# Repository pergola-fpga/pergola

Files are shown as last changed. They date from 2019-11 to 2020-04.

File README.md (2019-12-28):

# Pergola FPGA

The Pergola FPGA board is a low-cost, open-source FPGA development board featuring the Lattice ECP5 FPGA.

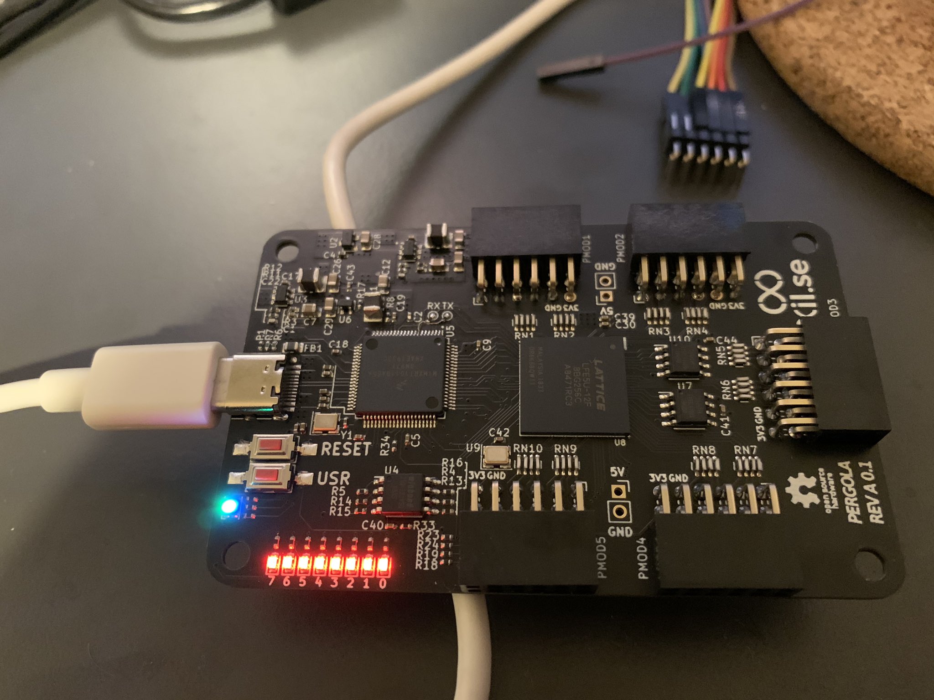
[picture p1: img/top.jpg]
Pergola FPGA top view


# Current status

## RevA 0.1

A handful of units have been built for initial test and bringup populated with LFE5U-12F-8BG256C.

It has been tested and works if the fixes below are applied.

### Errata:

- iMX ROM bootloader freezes because the UART RX pin is pulled
   low by the FPGA during boot. (FPGA pin is PL35B_VREF_1_6)
   A 4K7 pull-up is probably not enough, the voltage drops to 2.9V.
   Workaround: Bodge a 1K pull-up between UART_RX and 3V3.
- Wrong load caps for the xtal. Should be 20pF.
- SWD IO and CLK are swapped on the silk.
- IMX_BOOT_MODE_0 and IMX_BOOT_MODE_1 are swapped on the silk.
- A 1K pull-down is on the `~FPGA_HOLD~` net to allow the iMX to use the flash exclusively during boot-up.

# Firmware
TODO.

Currently I have a very ugly test project that can be loaded into the iMX's RAM using the ROM bootloader. This will open up a CDC interface that can be used to send a bitstream to the FPGA.

Currently working on porting the UF2 bootloader in order to update the firmware easily using USB and not having to use the SWD pins.

Current *horrible* hack is located over at [git.xil.se](https://git.xil.se/kbeckmann/pergola_fw) and contains a prebuilt binary.

The firmware will expose a cdc_acm device over USB. To program a bitstream, you simply have to write the number of bytes it is, followed by a newline (`\n`), followed by the bitstream.

# Getting started

- Clone my fork of the imx usb loader project:
```
git clone https://github.com/kbeckmann/imx_usb_loader && cd imx_usb_loader
```
- Checkout the `imxrt1010` branch:
```
git checkout imxrt1010
```
- Build it:
```
make
```
- Clone this repository and change to the firmware directory: (firmware is built from https://git.xil.se/kbeckmann/pergola_fw)
```
cd .. && git clone https://github.com/pergola-fpga/pergola && cd pergola/firmware
```
- Run the loader:
```
../../imx_usb_loader/imx_usb
```
. You might have to run it with `sudo`.
- Check `dmesg` to see if you got a cdc_acm device, e.g. `ttyACM0`
- Now you'll be able to send a bitstream to the board:
```
export ACM_DEVICE=/dev/ttyACM0
export PROGRAM_BIN=path/to/your/top.bin

# If you don't have setup udev rules
sudo chown $UID:$GID $ACM_DEVICE

# Configure the ACM device to be raw, this prevents weird stuff from happening when we send raw binary data.
stty -F $ACM_DEVICE 300 raw -clocal -echo icrnl;
sleep 0.01;
cat $ACM_DEVICE &;
echo -n "$(stat -c%s $PROGRAM_BIN)\n" > $ACM_DEVICE;
cp $PROGRAM_BIN $ACM_DEVICE; sync
```

- This should generate the following output more or less:
```
Reading 582369 bytes
READ_ID: ff ff ff ff 21 11 10 43

Done programming. FPGA_DONE=1
P E R G O L A

<bytes to load><\n>; Load bitstream to FPGA SRAM
```

- There is also an nmigen board definition in gateware/nmigen_wip/pergola.py

# How to contribute

Feel free to submit a PR, create an issue.

Discussion happens on [Gitter](https://gitter.im/pergola-fpga/Lobby) for the time being. You can also ping [@kbeckmann](https://twitter.com/kbeckmann) on Twitter.

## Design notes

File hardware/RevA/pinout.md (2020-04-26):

# PMOD Pinout RevA 0.1

```
-------- PMOD 1 ------ PMOD 2 ----
|                                 |
|                                 |P
|U                                |M
|S                                |O
|B                                |D
|                                 |3
|                                 |
-------- PMOD 5 ------ PMOD 4 ----

PMOD pinout, female header, front view

+--------------------------------------+
|3V3   GND      4      3      2      1 |
|3V3   GND      8      7      6      5 |
+--------------------------------------+

PMOD 1          TDP        TDP        TDP        TDP
+------------------------------------------------------+
|3V3   GND      PL20B      PL23B      PL26A      PL32B |
|3V3   GND      PL20A      PL23A      PL26B      PL32A |
+------------------------------------------------------+

PMOD 2          TDP        TDP        TDP        TDP
+------------------------------------------------------+
|3V3   GND      PL2A       PL5A       PL8B       PL14B |
|3V3   GND      PL2B       PL5B       PL8A       PL14A |
+------------------------------------------------------+

PMOD 3                                TDP
+------------------------------------------------------+
|3V3   GND      PT27A <DP> PT27B     PT22A      PT9B  |
|3V3   GND      PT29B <DP> PT29A     PT22B      PL11A |
+------------------------------------------------------+

PMOD 4          TDP
+------------------------------------------------------+
|3V3   GND      PT67A      PT60A      PT56A      PT49A |
|3V3   GND      PT67B      PT65B <DP> PT65A      PT53B |
+------------------------------------------------------+

PMOD 5          TDP        TDP        TDP        TDP
+------------------------------------------------------+
|3V3   GND      PR26A      PR23A      PR20A      PR14A |
|3V3   GND      PR26B      PR23B      PR20B      PR14B |
+------------------------------------------------------+

```

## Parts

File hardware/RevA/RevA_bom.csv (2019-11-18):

Reference | Quantity | Value | Footprint | Datasheet | LCSC | LCSC EUR | LCSC URL | Mouser | Mouser EUR | Mouser URL
C10 C15 C4 | 3 | 4u7 | Capacitor_SMD:C_0402_1005Metric |  | https://lcsc.com/product-detail/Multilayer-Ceramic-Capacitors-MLCC-SMD-SMT_SAMSUNG_CL21A226MOQNNNE_22uF-226-20-16V_C98190.html
C11 C14 | 2 | 4p7 | Capacitor_SMD:C_0402_1005Metric
C16 C20 C23 C3 C1 C17 C30 C33 C36 C38 C39 C31 C34 C32 C35 C37 C41 C42 C40 C43 C44 | 21 | 100n | Capacitor_SMD:C_0402_1005Metric
C19 C8 C13 C18 C9 C5 C2 | 7 | 220n | Capacitor_SMD:C_0402_1005Metric
C21 C22 | 2 | 22p | Capacitor_SMD:C_0402_1005Metric
C24 | 1 | 10u | Capacitor_SMD:C_0402_1005Metric |  | https://lcsc.com/product-detail/Multilayer-Ceramic-Capacitors-MLCC-SMD-SMT_SAMSUNG_CL21A226MOQNNNE_22uF-226-20-16V_C98190.html
C25 C27 C28 C7 C26 C29 C6 C12 | 8 | 22u | Capacitor_SMD:C_0805_2012Metric |  | C98190 | 0.0297 | https://lcsc.com/product-detail/Multilayer-Ceramic-Capacitors-MLCC-SMD-SMT_SAMSUNG_CL21A226MOQNNNE_22uF-226-20-16V_C98190.html
D1 | 1 | LED_ARGB | LED_SMD:LED_Cree-PLCC4_2x2mm_CW |  | C108793 | 0.0249 | https://lcsc.com/product-detail/Light-Emitting-Diodes-LED_FM-B2020RGBA-HG_C108793.html
D3 D4 D5 D6 D7 D8 D9 D2 | 8 | LED | LED_SMD:LED_0603_1608Metric |  | C84263 | 0.0111 | https://lcsc.com/product-detail/Light-Emitting-Diodes-LED_Red-LED-SMDLED-80-100mcd_C84263.html
FB1 | 1 | Ferrite_Bead | Inductor_SMD:L_0805_2012Metric |  | C88993 | 0.0183 | https://lcsc.com/product-detail/Ferrite-Beads-And-Chips_muRata_BLM21PG220SN1D_22R-25_C88993.html
H1 H2 H4 H3 | 4 | DNP | MountingHole:MountingHole_3.5mm
J1 | 1 | USB_C_Receptacle_USB2.0 | Connector_USB_Extra:USB_C_Receptacle_GT-USB-7010 | https://www.usb.org/sites/default/files/documents/usb_type-c.zip | C165948 | 0.2221 | https://lcsc.com/product-detail/USB-Type-C_Korean-Hroparts-Elec-TYPE-C-31-M-12_C165948.html
J2 | 1 | DNP Conn_02x02_Odd_Even | Connector_PinHeader_2.54mm:PinHeader_2x02_P2.54mm_Vertical_SMD
J3 J5 | 2 | DNP Conn_01x02 | Connector_PinSocket_2.54mm:PinSocket_1x02_P2.54mm_Vertical
J4 | 1 | DNP Conn_02x03_Odd_Even | Connector_PinHeader_2.54mm:PinHeader_2x03_P2.54mm_Vertical_SMD
JP2 JP1 JP3 JP4 JP5 JP6 JP9 JP8 JP7 | 9 | 4K7 | ecp5board:JP_3_0402_1005Metric |  | C105871 | 0.0005 | https://lcsc.com/product-detail/Chip-Resistor-Surface-Mount_4-7KR-4701-1_C105871.html
L2 L1 L3 | 3 | 4u7 1A | ecp5board:L_1008_1210 |  | C90319 | 0.0691 | https://lcsc.com/product-detail/Inductors-SMD_Taiyo-Yuden_CBC3225T4R7MR_Taiyo-Yuden-CBC3225T4R7MR_C90319.html
LOGO1 | 1 | Logo_Open_Hardware_Small | Symbol:OSHW-Logo_5.7x6mm_SilkScreen | ~
LOGO2 | 1 | Logo_Open_Hardware_Small | ecp5board:logo | ~
LOGO3 | 1 | Logo_Open_Hardware_Small | ecp5board:xil_logo_new | ~
PMOD1 PMOD2 PMOD3 PMOD4 PMOD5 | 5 | Conn_02x06_Top_Bottom | ecp5board:PMOD_Socket_2x06_P2.54mm_Horizontal |  | C239357 | 0.1299 | https://lcsc.com/product-detail/Pin-Header-Female-Header_Changjiang-Connectors-A2541HWR-2x6P_C239357.html
R1 | 1 | 100K | Resistor_SMD:R_0402_1005Metric
R10 | 1 | 18K | Resistor_SMD:R_0402_1005Metric
R12 | 1 | 3K3 | Resistor_SMD:R_0402_1005Metric
R2 R17 R3 R14 R13 R16 R15 | 7 | 10K | Resistor_SMD:R_0402_1005Metric
R35 | 1 | DNP | Resistor_SMD:R_0402_1005Metric
R4 | 1 | 1K | Resistor_SMD:R_0402_1005Metric
R5 R19 R18 R23 R24 R34 R25 R26 R27 R28 R29 R30 R31 R32 R20 R21 R22 R33 | 18 | 4K7 | Resistor_SMD:R_0402_1005Metric
R6 R7 | 2 | 5K1 | Resistor_SMD:R_0402_1005Metric
R8 | 1 | 30K | Resistor_SMD:R_0402_1005Metric
R9 R11 | 2 | 15K | Resistor_SMD:R_0402_1005Metric
RN2 RN4 RN3 RN6 RN8 RN7 RN10 RN9 RN1 RN5 | 10 | 22R_x4 | Resistor_SMD:R_Array_Convex_4x0603 |  | C309446 | 0.0075 | https://lcsc.com/product-detail/Others_YAGEO-AF124-JR-0722RL_C309446.html
SW1 SW2 | 2 | SW_Push | Button_Switch_SMD:SW_SPST_FSMSM |  | C118141 | 0.0307 | https://lcsc.com/product-detail/Tactile-Switches_Korean-Hroparts-Elec-K2-1107ST-A4SW-06_C118141.html
TP1 | 1 | RX | TestPoint:TestPoint_Pad_D1.0mm
TP2 | 1 | TX | TestPoint:TestPoint_Pad_D1.0mm
U1 U3 | 2 | SY8120B1ABC | Package_TO_SOT_SMD:SOT-23-6 | https://datasheet.lcsc.com/szlcsc/1811081220_Silergy-Corp-SY8120B1ABC_C88474.pdf | C88474 | 0.0557 | https://lcsc.com/product-detail/DC-DC-Converters_Silergy_SY8120B1ABC_SY8120B1ABC_C88474.html
U2 | 1 | XC6206P25 | Package_TO_SOT_SMD:SOT-23 | https://datasheet.lcsc.com/szlcsc/1810271312_Torex-Semicon-XC6206P252MR_C15906.pdf | C15906 | 0.0529 | https://lcsc.com/product-detail/Low-Dropout-Regulators-LDO_XC6206P252MR_C15906.html
U4 | 1 | SPI Flash W25Q128JVSIQ | ecp5board:SOA008-150-208mil | https://datasheet.lcsc.com/szlcsc/1811142111_Winbond-Elec-W25Q128JVSIQ_C97521.pdf | C97521 | 0.4692 | https://lcsc.com/product-detail/FLASH_Winbond-Elec-W25Q128JVSIQTR_C97521.html
U5 | 1 | MIMXRT1011DAE5A | Package_QFP:LQFP-80_12x12mm_P0.5mm |  |  |  |  | 771-MIMXRT1011DAE5A | 2.95 | https://www.mouser.se/ProductDetail/NXP-Semiconductors/MIMXRT1011DAE5A
U6 | 1 | MAX803SQ308T1G | Package_TO_SOT_SMD:SOT-323_SC-70 | https://datasheet.lcsc.com/szlcsc/1809111625_ON-Semicon-MAX803SQ308T1G_C233650.pdf | C233650 | 0.1589 | https://lcsc.com/product-detail/Microprocessor-Microcontroller-Supervisors_ON-Semicon_MAX803SQ308T1G_ON-Semicon-ON-MAX803SQ308T1G_C233650.html
U7 U10 | 2 | SPI RAM LY68L6400SLIT | Package_SO:SOIC-8_3.9x4.9mm_P1.27mm | https://datasheet.lcsc.com/szlcsc/1809140531_Lyontek-Inc-LY68L6400SLIT_C261881.pdf | C261881 | 0.4665 | https://lcsc.com/product-detail/RAM_Lyontek-Inc-LY68L6400SLIT_C261881.html
U8 | 1 | LFE5U-12F-6BG256C | w_smd_bga:cabga256 |  |  |  |  | 842-LFE5U12F6BG256C | 4.96 | https://www.mouser.se/ProductDetail/Lattice/LFE5U-12F-6BG256C
U9 | 1 | 16MHz 20ppm | Crystal:Crystal_SMD_3225-4Pin_3.2x2.5mm |  | C387369 | 0.2984 | https://lcsc.com/product-detail/SMD-Oscillators-XO_Shenzhen-SCTF-Elec-S3D16-000000B20F30T_C387369.html
Y1 | 1 | 24MHz 10ppm | Crystal:Crystal_SMD_3225-4Pin_3.2x2.5mm |  | C164058 | 0.0642 | https://lcsc.com/product-detail/SMD-Crystal-Resonators_Zhejiang-Abel-Elec-SMD-3225-4P24MHZ12PF10PPM-40-85_C164058.html

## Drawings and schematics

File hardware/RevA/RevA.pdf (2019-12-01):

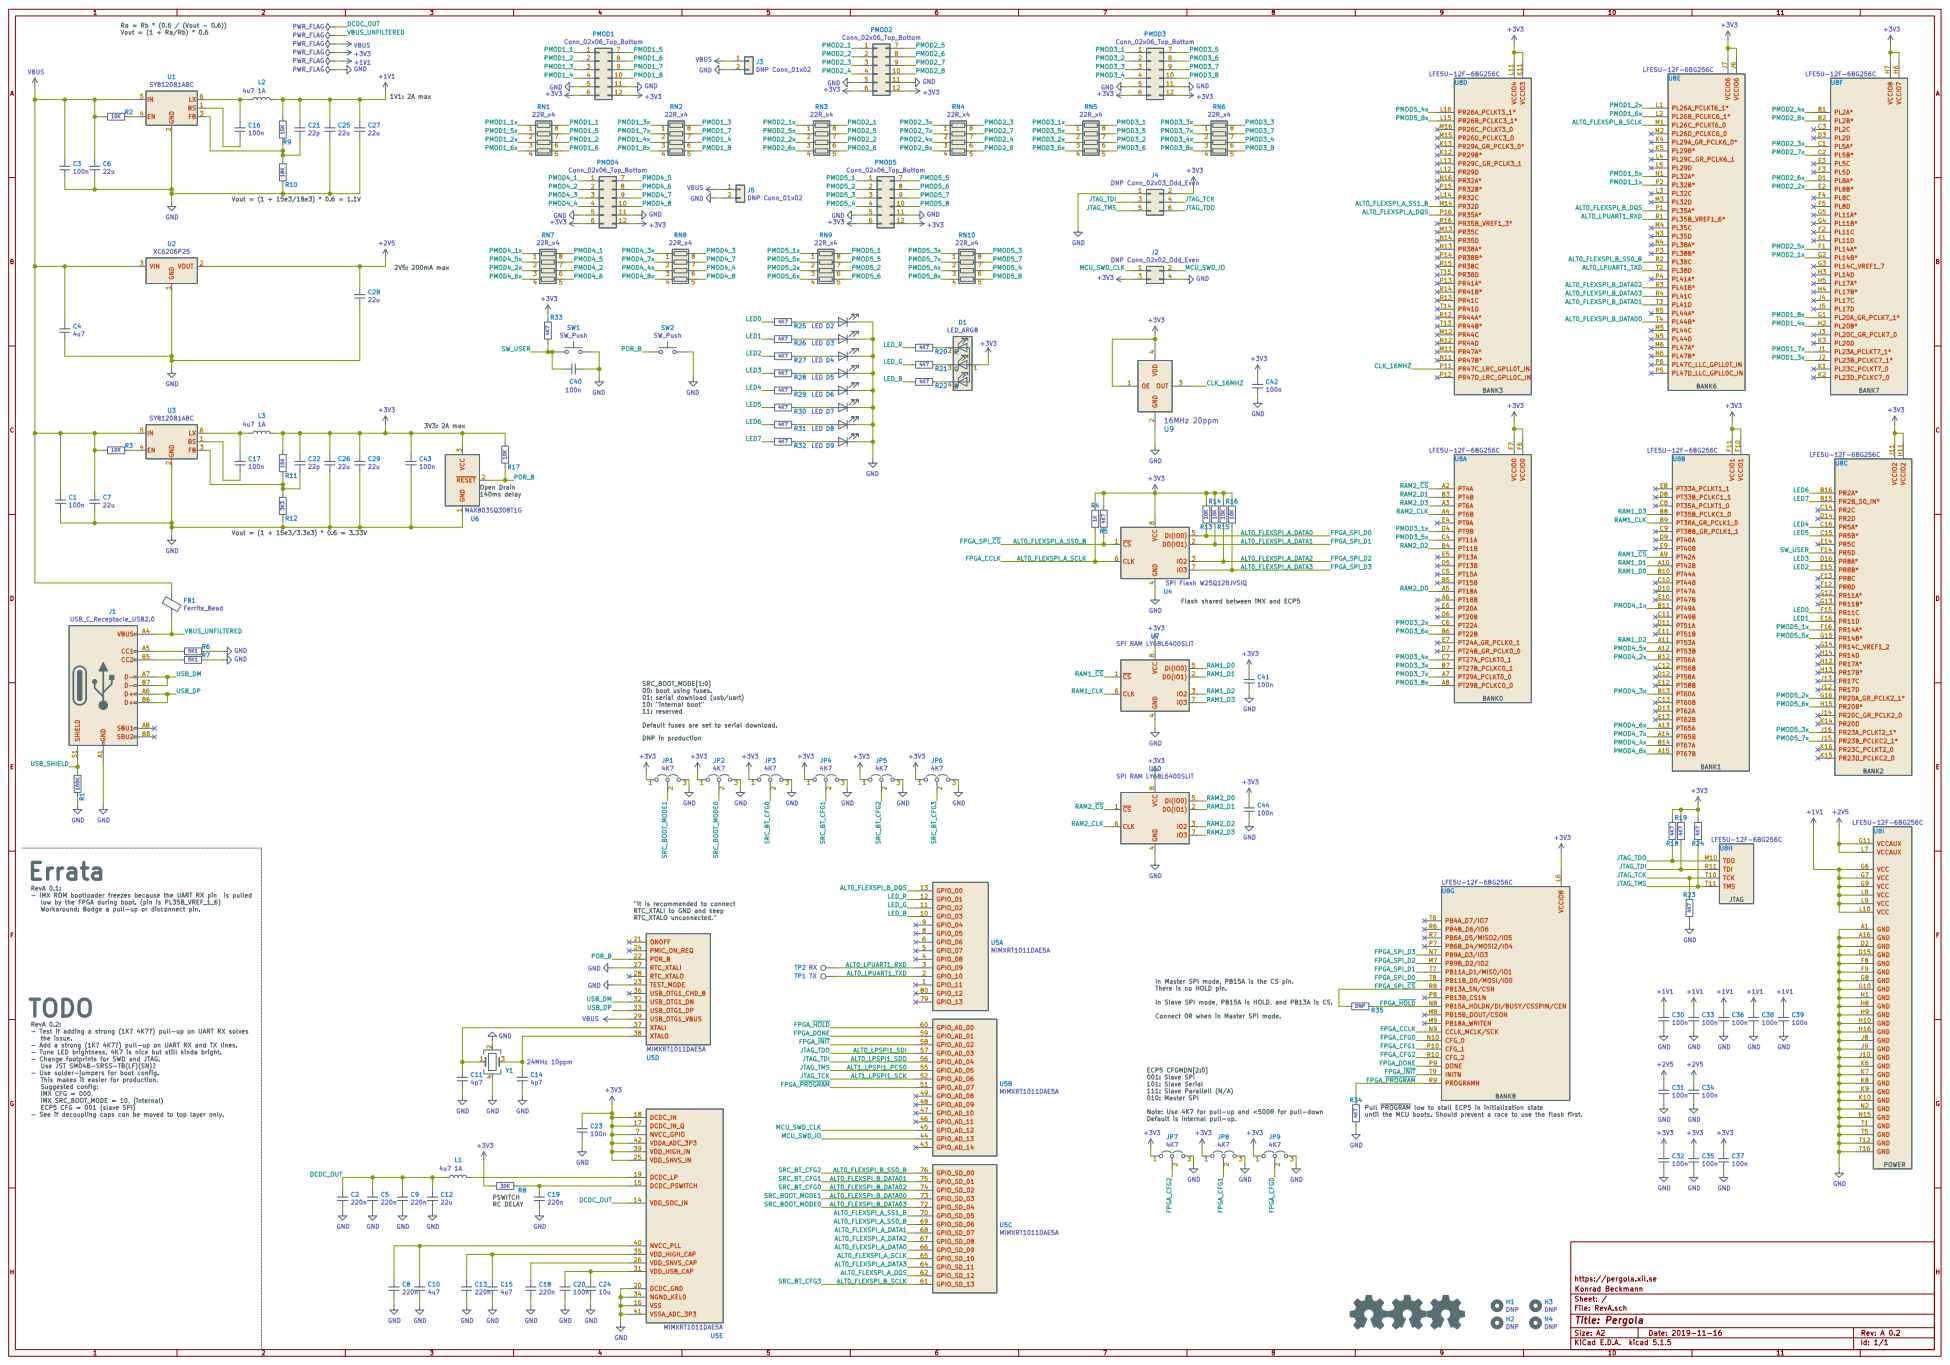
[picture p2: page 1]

Flash shared between iMX and ECP5
GND

SRC_BOOT_MODE[1:0]
00: boot using fuses.
01: serial download (usb/uart) 10: "internal boot" 11: reserved Default fuses are set to serial download.

"It is recommended to connect RTC_XTALI to GND and keep RTC_XTALO unconnected." Errata

RevA 0.1: - iMX ROM bootloader freezes because the UART RX pin is pulled

low by the FPGA during boot. (pin is PL35B_VREF_1_6)
Workaround: Bodge a pull-up or disconnect pin.

In Master SPI mode, PB15A is the CS pin.
There is no HOLD pin.

RevA 0.2: - Test if adding a strong (1K? 4K7?) pull-up on UART RX solves

the issue. - Add a strong (1K? 4K7?) pull-up on UART RX and TX lines.

- Tune LED brightness. 4K7 is nice but still kinda bright.
- Change footprints for SWD and JTAG.
Use JST SM04B-SRSS-TB(LF)(SN)?
- Use solder-jumpers for boot config.
This makes it easier for production.
Suggested config:
iMX CFG = 000,
iMX SRC_BOOT_MODE = 10, (internal)
ECP5 CFG = 001 (slave SPI)
- See if decoupling caps can be moved to top layer only.

ECP5 CFGMDN[2:0] 001: Slave SPI 101: Slave Serial 111: Slave Parallell (N/A) 010: Master SPI Note: Use 4K7 for pull-up and <500R for pull-down

Default is internal pull-up.

until the MCU boots. Should prevent a race to use the flash first.

https://pergola.xil.se
File: RevA.sch Sheet: / Konrad Beckmann

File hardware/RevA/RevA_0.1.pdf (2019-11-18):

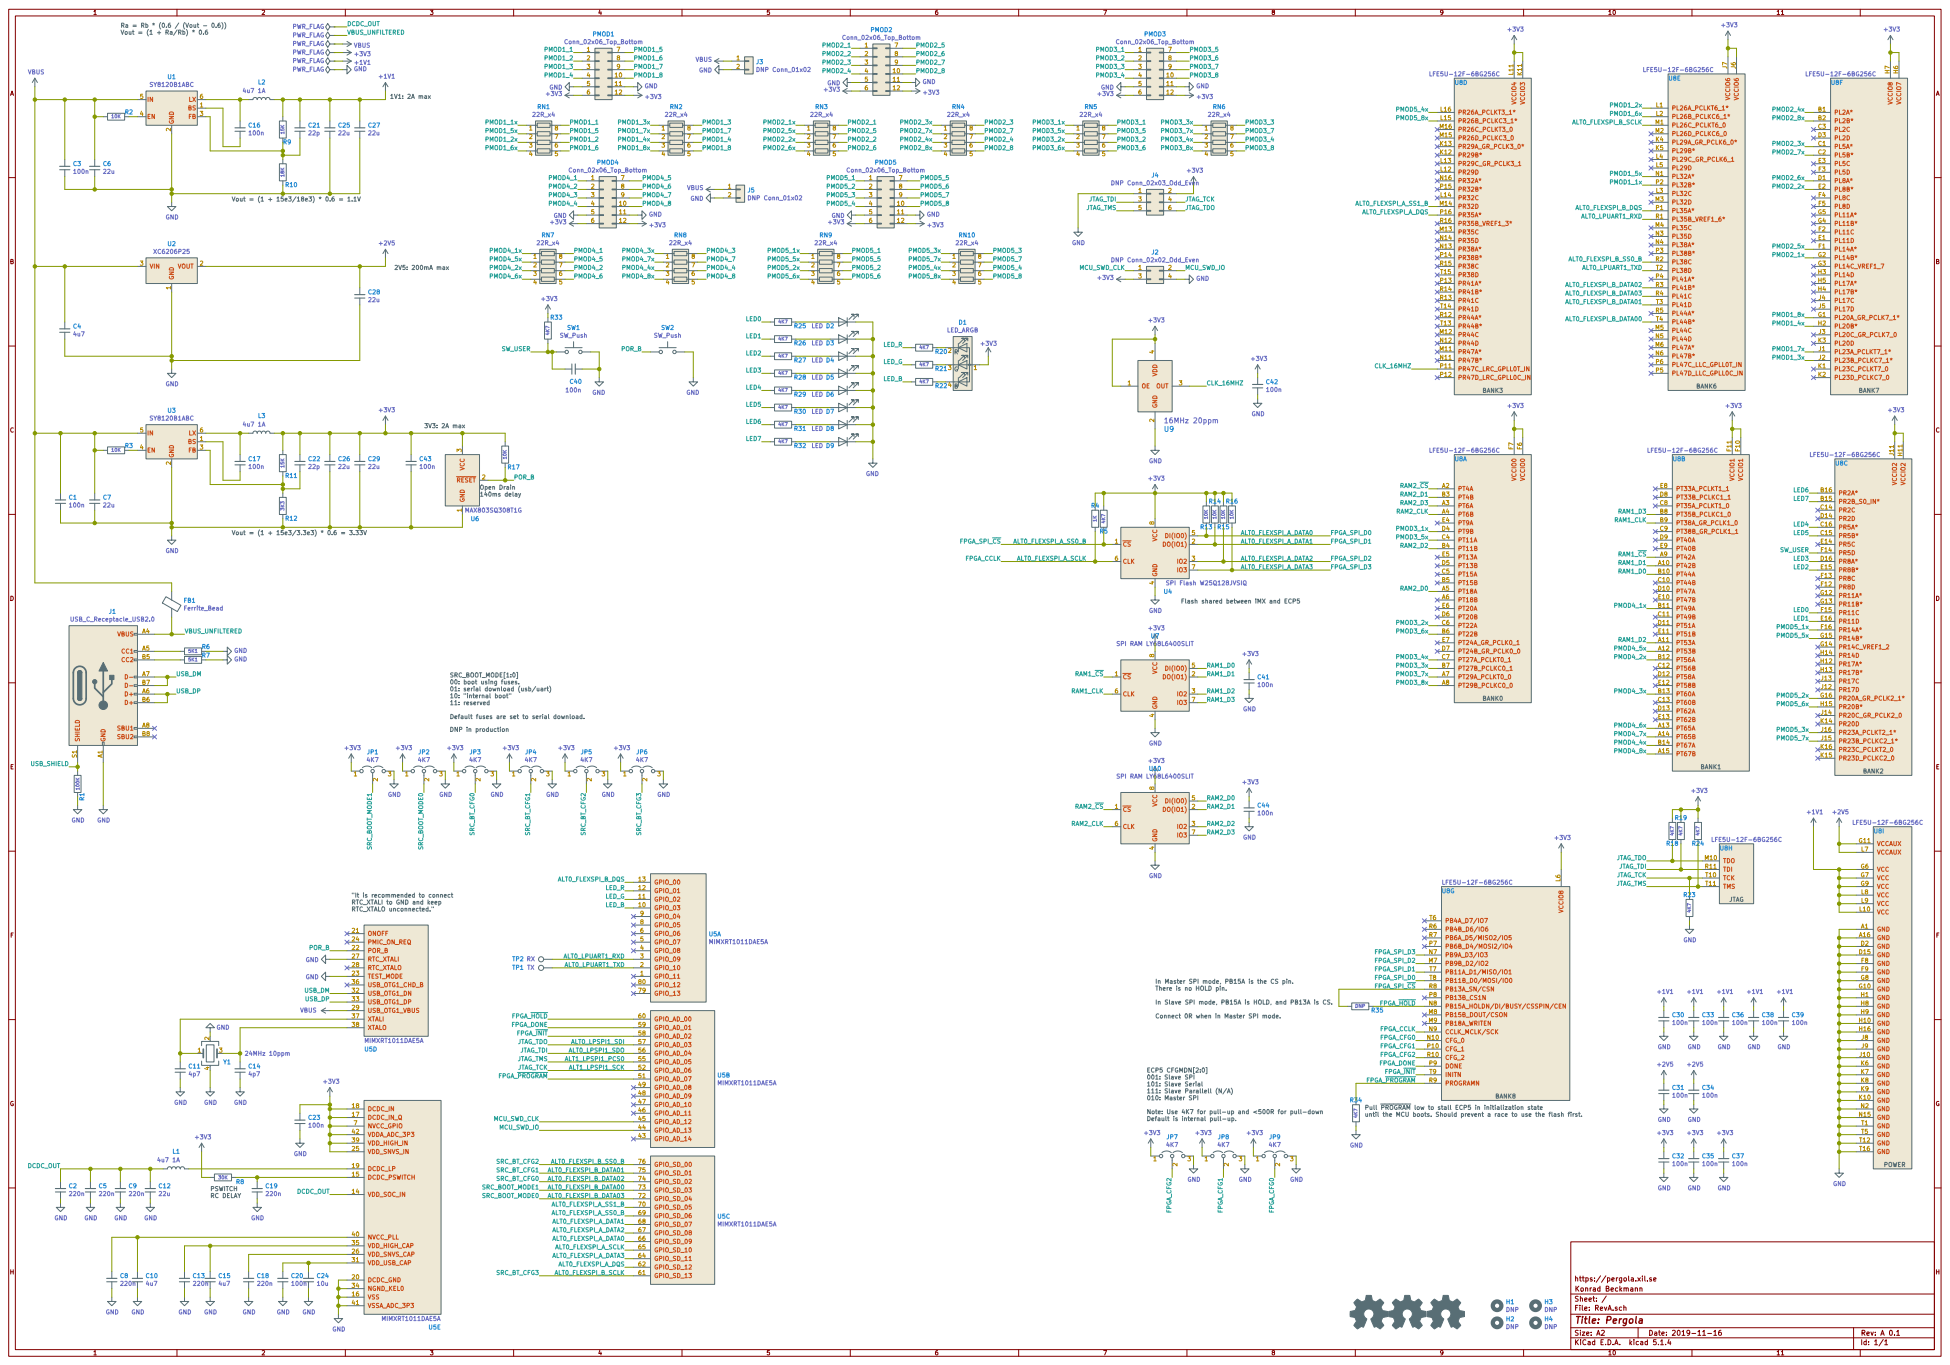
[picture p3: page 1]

Flash shared between iMX and ECP5 Open Drain
140ms delay

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

In Master SPI mode, PB15A is the CS pin.
There is no HOLD pin.

In Slave SPI mode, PB15A is HOLD, and PB13A is CS. Connect 0R when in Master SPI mode.

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

Pull PROGRAM low to stall ECP5 in initialization state
until the MCU boots. Should prevent a race to use the flash first.

Default is internal pull-up.

https://pergola.xil.se
File: RevA.sch Sheet: / Konrad Beckmann

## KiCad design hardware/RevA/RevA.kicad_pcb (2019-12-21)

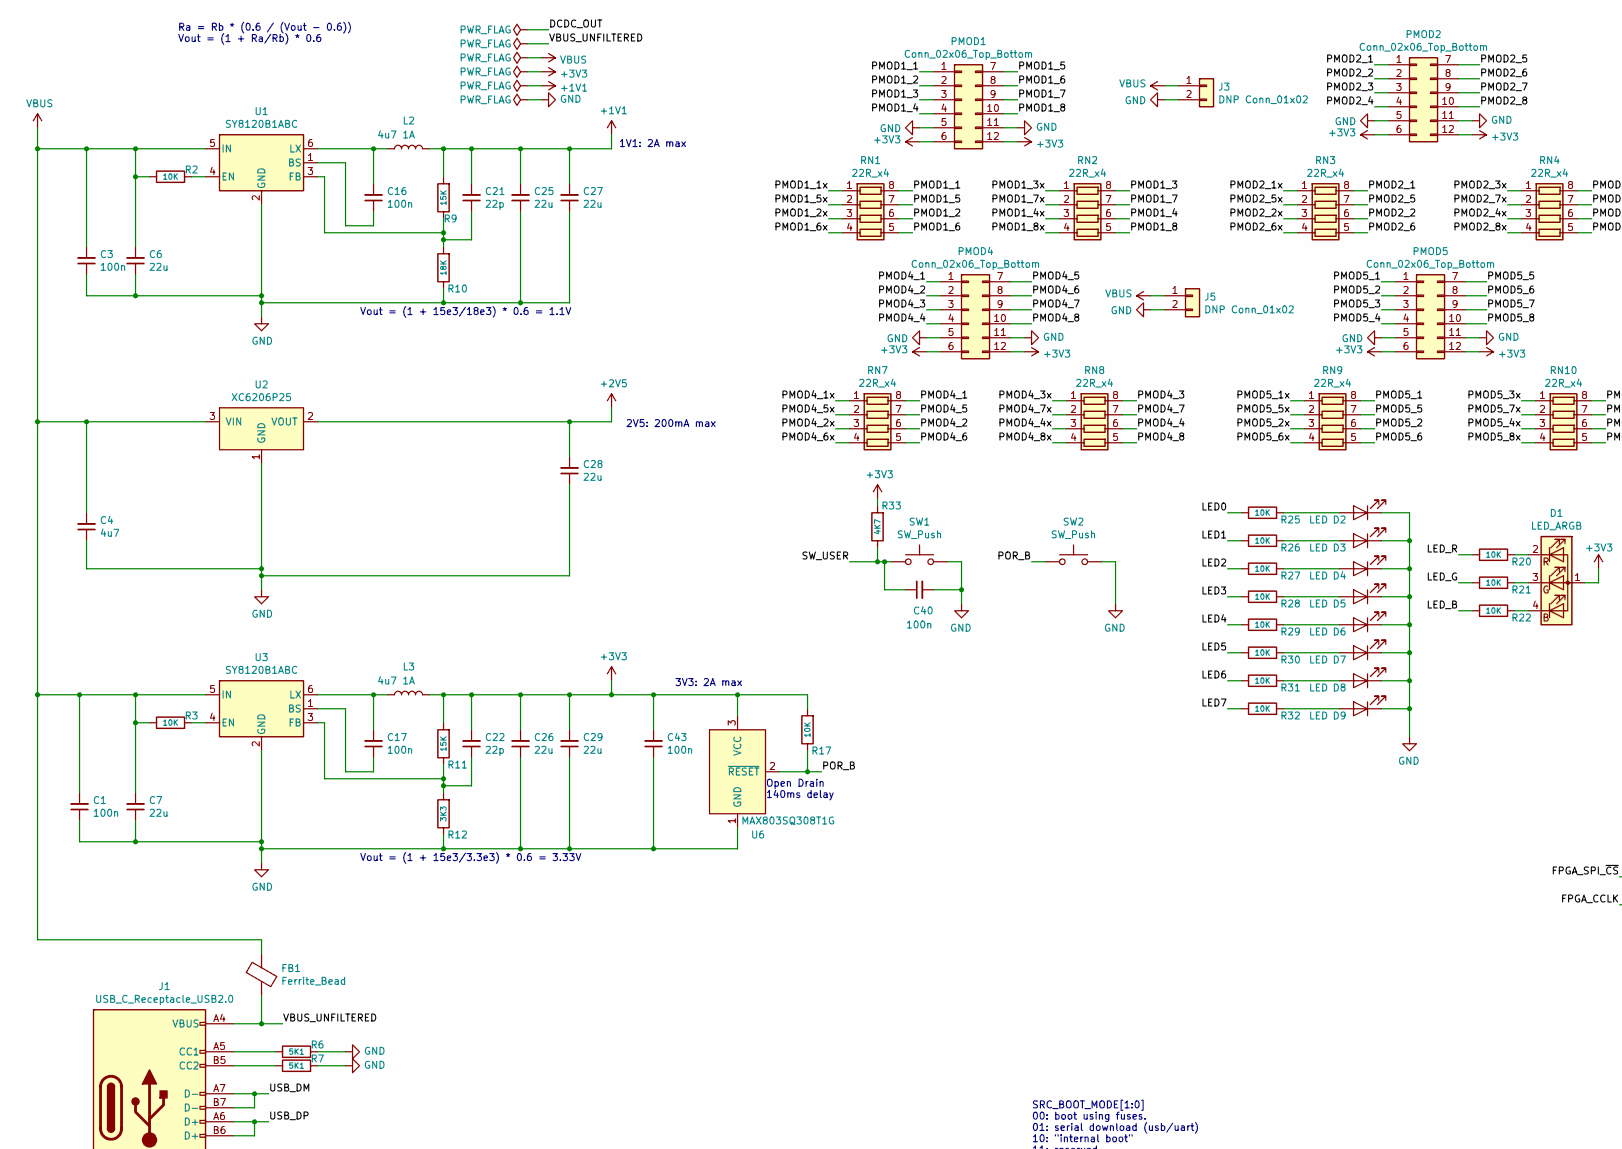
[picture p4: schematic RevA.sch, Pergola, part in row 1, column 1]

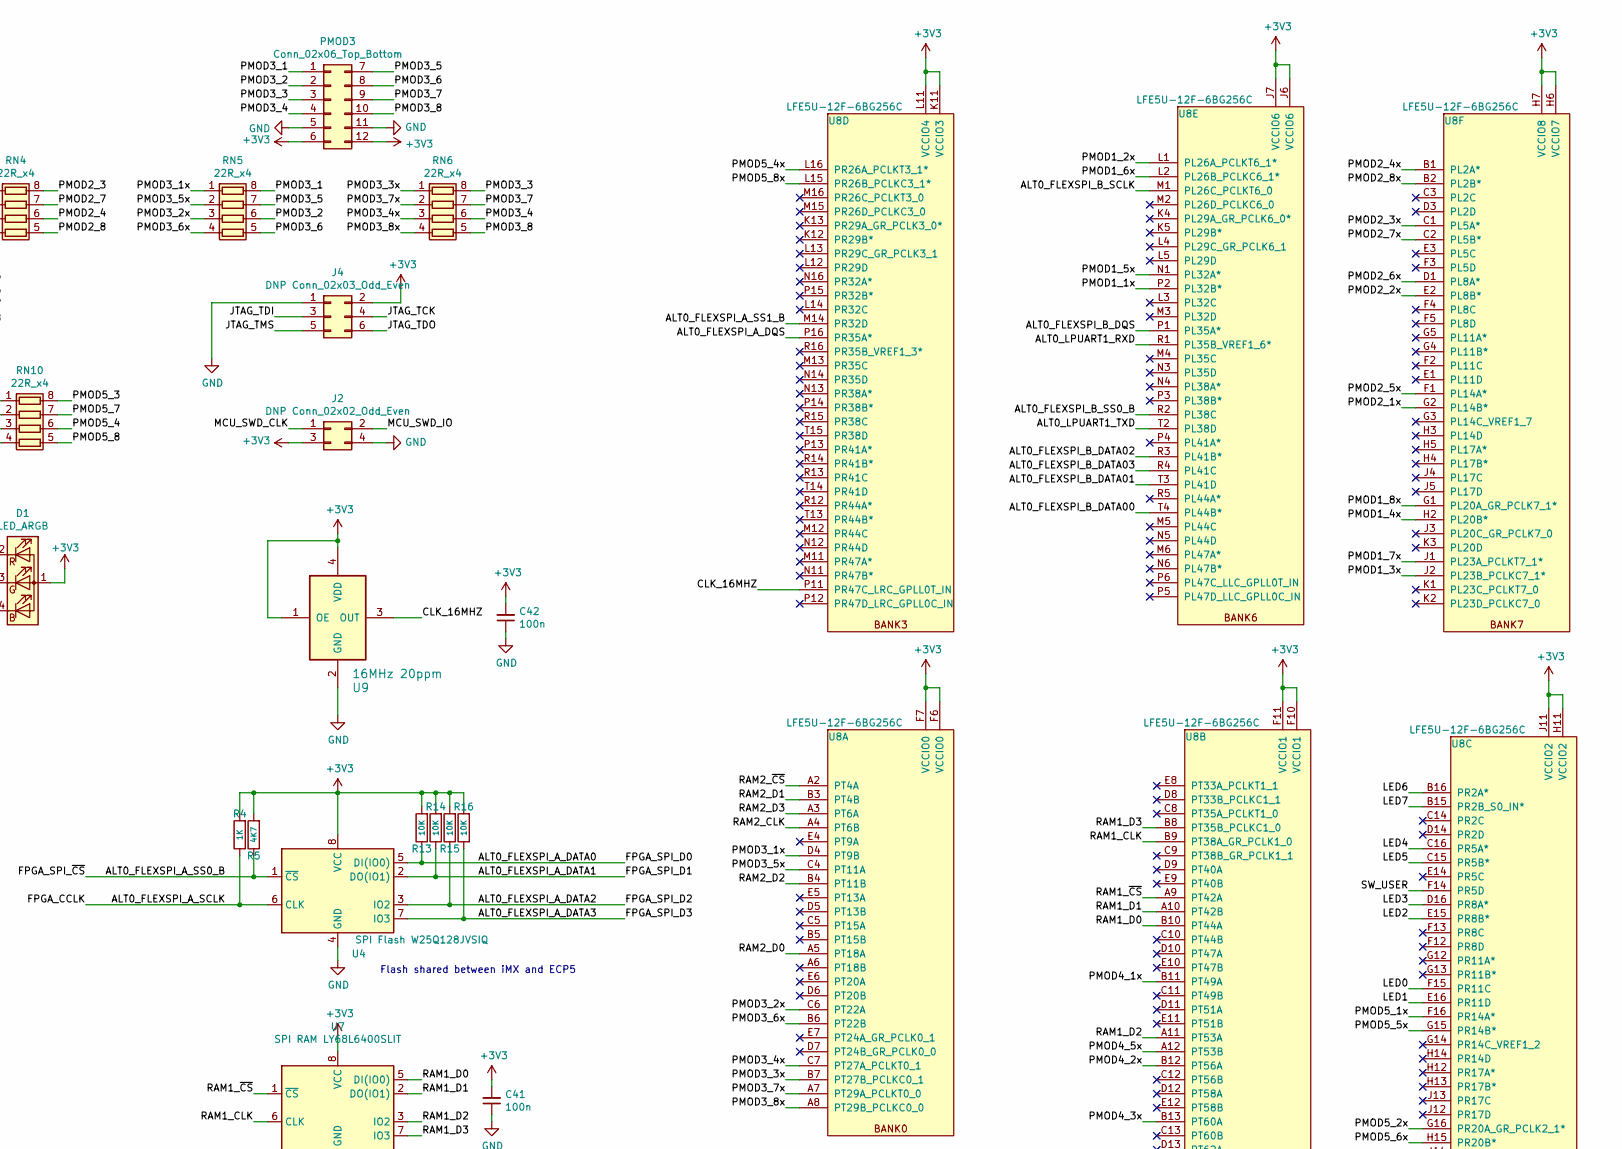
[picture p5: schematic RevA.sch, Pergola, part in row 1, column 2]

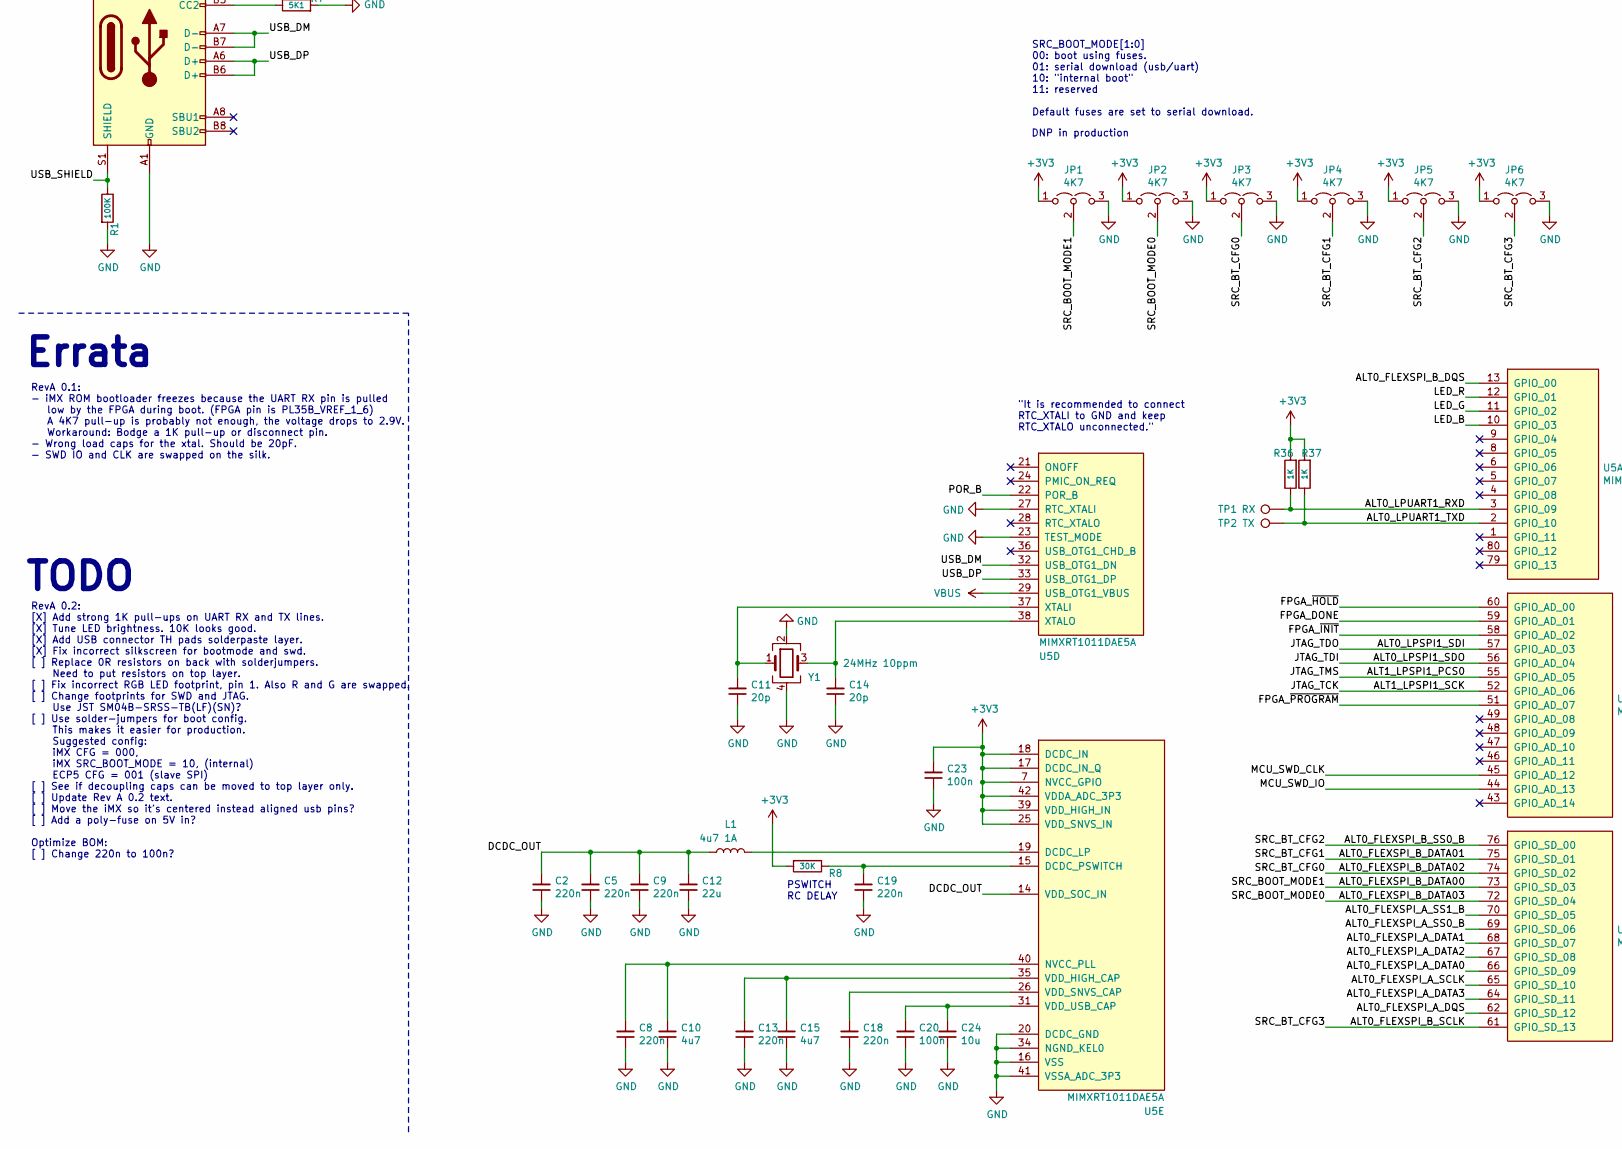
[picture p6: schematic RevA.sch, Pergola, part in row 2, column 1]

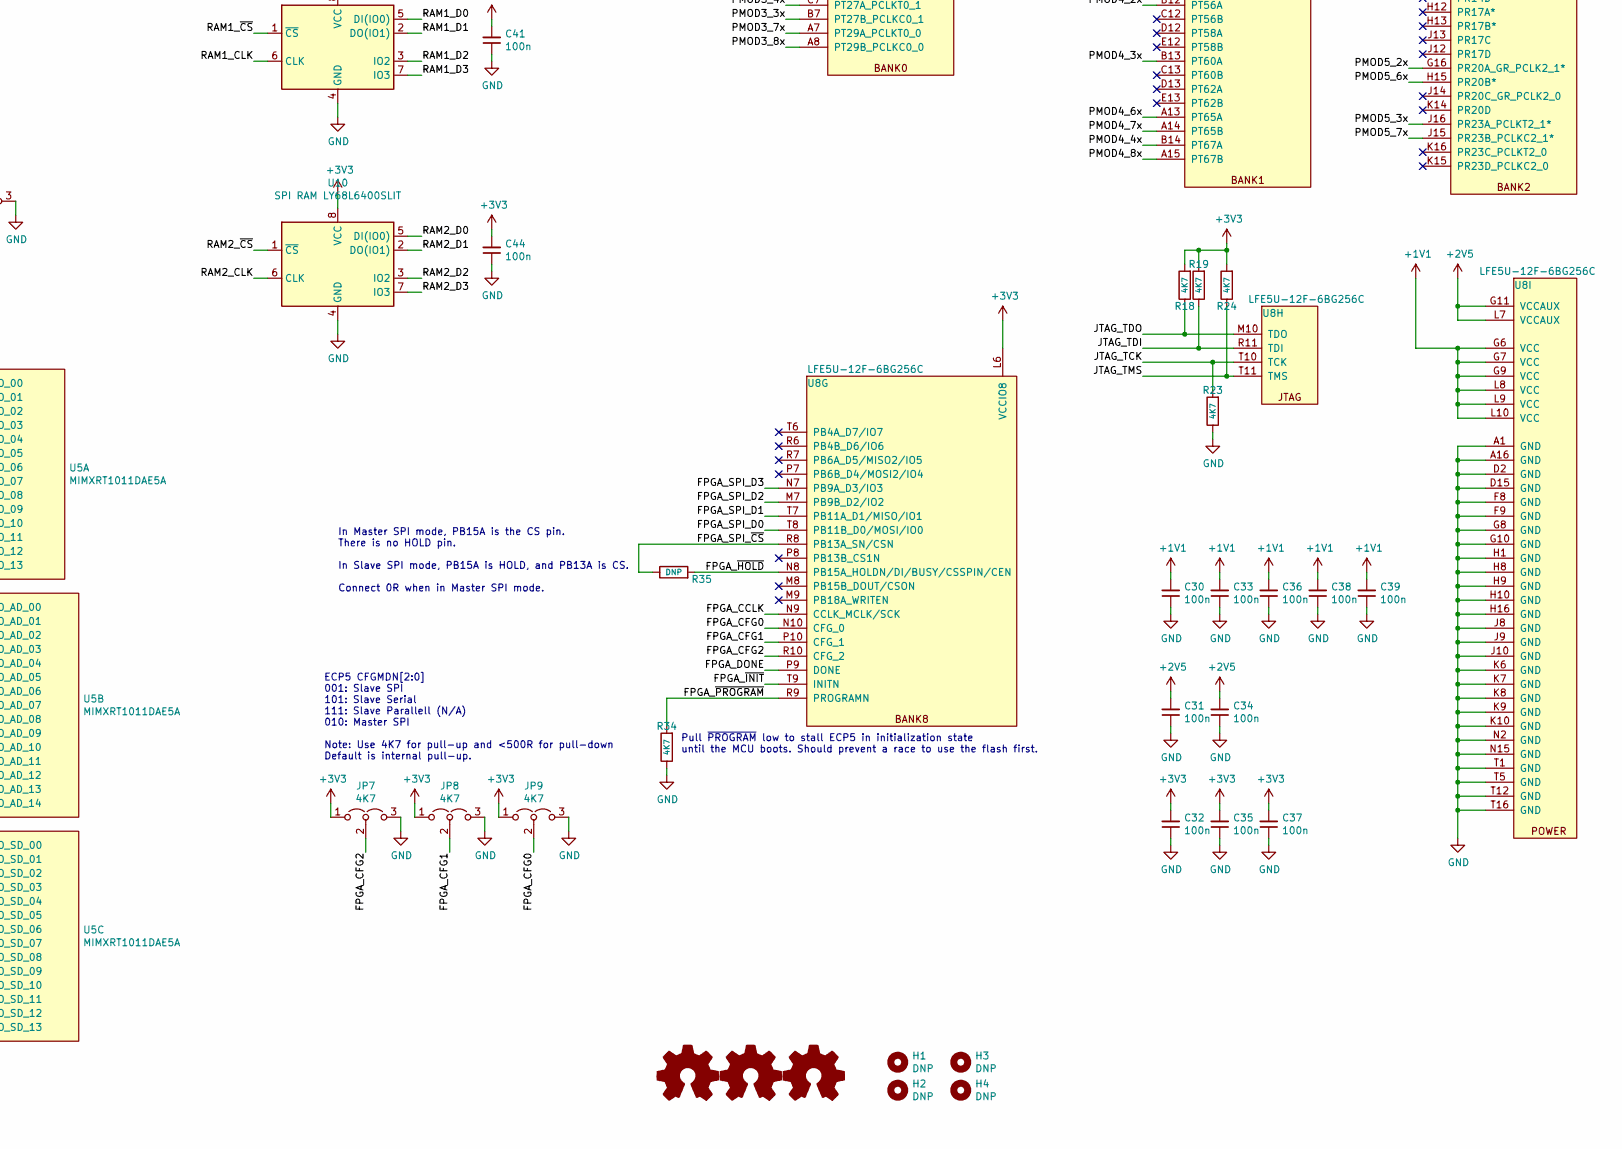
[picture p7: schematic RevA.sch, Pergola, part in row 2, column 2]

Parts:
C1, C3, C16, C17, C20, C23, C30, C31, C32, C33, C34, C35, C36, C37, C38, C39, C40, C41, C42, C43, C44: 100n; C_0402_1005Metric
C2, C5, C8, C9, C13, C18, C19: 220n; C_0402_1005Metric
C4, C10, C15: 4u7; C_0402_1005Metric
C6, C7, C12, C25, C26, C27, C28, C29: 22u; C_0805_2012Metric; LCSC C98190
C11, C14: 20p; C_0402_1005Metric
C21, C22: 22p; C_0402_1005Metric
C24: 10u; C_0402_1005Metric
D1: LED_ARGB; LED_Cree-PLCC4_2x2mm_CW; LCSC C108793
D2, D3, D4, D5, D6, D7, D8, D9: LED; LED_0603_1608Metric; LCSC C84263
FB1: Ferrite_Bead; L_0805_2012Metric; LCSC C88993
H1, H2, H3, H4: DNP; MountingHole_3.5mm
J1: USB_C_Receptacle_USB2.0; USB_C_Receptacle_GT-USB-7010; LCSC C165948
J2: DNP Conn_02x02_Odd_Even; PinHeader_2x02_P2.54mm_Vertical_SMD
J3, J5: DNP Conn_01x02; PinSocket_1x02_P2.54mm_Vertical
J4: DNP Conn_02x03_Odd_Even; PinHeader_2x03_P2.54mm_Vertical_SMD
JP1, JP2, JP3, JP4, JP5, JP6, JP7, JP8, JP9: 4K7; JP_3_0402_1005Metric; LCSC C105871
L1, L2, L3: 4u7 1A; L_1008_1210; LCSC C90319
LOGO1: Logo_Open_Hardware_Small; OSHW-Logo_5.7x6mm_SilkScreen
LOGO2: Logo_Open_Hardware_Small; logo
LOGO3: Logo_Open_Hardware_Small; xil_logo_new
PMOD1, PMOD2, PMOD3, PMOD4, PMOD5: Conn_02x06_Top_Bottom; PMOD_Socket_2x06_P2.54mm_Horizontal; LCSC C239357
R1: 100K; R_0402_1005Metric
R2, R3, R13, R14, R15, R16, R17, R20, R21, R22, R25, R26, R27, R28, R29, R30, R31, R32: 10K; R_0402_1005Metric
R4, R36, R37: 1K; R_0402_1005Metric
R5, R18, R19, R23, R24, R33, R34: 4K7; R_0402_1005Metric
R6, R7: 5K1; R_0402_1005Metric
R8: 30K; R_0402_1005Metric
R9, R11: 15K; R_0402_1005Metric
R10: 18K; R_0402_1005Metric
R12: 3K3; R_0402_1005Metric
R35: DNP; R_0402_1005Metric
RN1, RN2, RN3, RN4, RN5, RN6, RN7, RN8, RN9, RN10: 22R_x4; R_Array_Convex_4x0603; LCSC C309446
SW1, SW2: SW_Push; SW_SPST_FSMSM; LCSC C118141
TP1: RX; TestPoint_Pad_D1.0mm
TP2: TX; TestPoint_Pad_D1.0mm
U1, U3: SY8120B1ABC; SOT-23-6; LCSC C88474
U2: XC6206P25; SOT-23; LCSC C15906
U4: SPI Flash W25Q128JVSIQ; SOA008-150-208mil; LCSC C97521
U5: MIMXRT1011DAE5A; LQFP-80_12x12mm_P0.5mm; Mouser 771-MIMXRT1011DAE5A
U6: MAX803SQ308T1G; SOT-323_SC-70; LCSC C233650
U7, U10: SPI RAM LY68L6400SLIT; SOIC-8_3.9x4.9mm_P1.27mm; LCSC C261881
U8: LFE5U-12F-6BG256C; cabga256; Mouser 842-LFE5U12F6BG256C
U9: 16MHz 20ppm; Crystal_SMD_3225-4Pin_3.2x2.5mm; LCSC C387369
Y1: 24MHz 10ppm; Crystal_SMD_3225-4Pin_3.2x2.5mm; LCSC C164058

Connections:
+1V1: C21.2, C25.2, C27.2, C30.2, C33.2, C36.2, C38.2, C39.2, L2.2, R9.2, U8.G6 (VCC), U8.G7 (VCC), U8.G9 (VCC), U8.L8 (VCC), U8.L9 (VCC), U8.L10 (VCC)
+2V5: C28.2, C31.2, C34.2, U2.2 (VOUT), U8.G11 (VCCAUX), U8.L7 (VCCAUX)
+3V3: C22.2, C23.2, C26.2, C29.2, C32.2, C35.2, C37.2, C41.2, C42.2, C43.2, C44.2, D1.1 (A), J2.3, J4.2, JP1.1 (A), JP2.1 (A), JP3.1 (A), JP4.1 (A), JP5.1 (A), JP6.1 (A), JP7.1 (A), JP8.1 (A), JP9.1 (A), L3.2, PMOD1.6, PMOD1.12, PMOD2.6, PMOD2.12, PMOD3.6, PMOD3.12, PMOD4.6, PMOD4.12, PMOD5.6, PMOD5.12, R4.2, R5.2, R8.2, R11.2, R13.2, R14.2, R15.2, R16.2, R17.2, R18.2, R19.2, R24.2, R33.2, R36.2, R37.2, U4.8 (VCC), U5.7 (NVCC_GPIO), U5.17 (DCDC_IN_Q), U5.18 (DCDC_IN), U5.25 (VDD_SNVS_IN), U5.39 (VDD_HIGH_IN), U5.42 (VDDA_ADC_3P3), U5.50 (NVCC_GPIO), U5.63 (NVCC_GPIO), U5.71 (NVCC_GPIO), U6.3 (VCC), U7.8 (VCC), U8.F6 (VCCIO0), U8.F7 (VCCIO0), U8.F10 (VCCIO1), U8.F11 (VCCIO1), U8.H6 (VCCIO7), U8.H7 (VCCIO8), U8.H11 (VCCIO2), U8.J6 (VCCIO6), U8.J7 (VCCIO6), U8.J11 (VCCIO2), U8.K11 (VCCIO3), U8.L6 (VCCIO8), U8.L11 (VCCIO4), U9.1 (OE), U9.4 (VDD), U10.8 (VCC)
/ALT0_FLEXSPI_A_DATA0: R13.1, U4.5 (DI(IO0)), U5.66 (GPIO_SD_09), U8.T8 (PB11B_D0/MOSI/IO0)
/ALT0_FLEXSPI_A_DATA1: R14.1, U4.2 (DO(IO1)), U5.68 (GPIO_SD_07), U8.T7 (PB11A_D1/MISO/IO1)
/ALT0_FLEXSPI_A_DATA2: R15.1, U4.3 (IO2), U5.67 (GPIO_SD_08), U8.M7 (PB9B_D2/IO2)
/ALT0_FLEXSPI_A_DATA3: R16.1, U4.7 (IO3), U5.64 (GPIO_SD_11), U8.N7 (PB9A_D3/IO3)
/ALT0_FLEXSPI_A_DQS: U5.62 (GPIO_SD_12), U8.P16 (PR35A*)
/ALT0_FLEXSPI_A_SCLK: R4.1, U4.6 (CLK), U5.65 (GPIO_SD_10), U8.N9 (CCLK_MCLK/SCK)
/ALT0_FLEXSPI_A_SS0_B: R5.1, R35.1, U4.1 (~CS), U5.69 (GPIO_SD_06), U8.R8 (PB13A_SN/CSN)
/ALT0_FLEXSPI_A_SS1_B: U5.70 (GPIO_SD_05), U8.M14 (PR32D)
/ALT0_FLEXSPI_B_DATA00: JP1.2 (C), U5.73 (GPIO_SD_03), U8.T4 (PL44B*)
/ALT0_FLEXSPI_B_DATA01: JP4.2 (C), U5.75 (GPIO_SD_01), U8.T3 (PL41D)
/ALT0_FLEXSPI_B_DATA02: JP3.2 (C), U5.74 (GPIO_SD_02), U8.R3 (PL41B*)
/ALT0_FLEXSPI_B_DATA03: JP2.2 (C), U5.72 (GPIO_SD_04), U8.R4 (PL41C)
/ALT0_FLEXSPI_B_DQS: U5.13 (GPIO_00), U8.P1 (PL35A*)
/ALT0_FLEXSPI_B_SCLK: JP6.2 (C), U5.61 (GPIO_SD_13), U8.M1 (PL26C_PCLKT6_0)
/ALT0_FLEXSPI_B_SS0_B: JP5.2 (C), U5.76 (GPIO_SD_00), U8.R2 (PL38C)
/ALT0_LPSPI1_SDI: J4.6, R18.1, U5.57 (GPIO_AD_03), U8.M10 (TDO)
/ALT0_LPSPI1_SDO: J4.3, R19.1, U5.56 (GPIO_AD_04), U8.R11 (TDI)
/ALT0_LPUART1_RXD: R36.1, TP1.1, U5.3 (GPIO_09), U8.R1 (PL35B_VREF1_6*)
/ALT0_LPUART1_TXD: R37.1, TP2.1, U5.2 (GPIO_10), U8.T2 (PL38D)
/ALT1_LPSPI1_PCS0: J4.5, R24.1, U5.55 (GPIO_AD_05), U8.T11 (TMS)
/ALT1_LPSPI1_SCK: J4.4, R23.2, U5.52 (GPIO_AD_06), U8.T10 (TCK)
/CLK_16MHZ: U8.P11 (PR47C_LRC_GPLL0T_IN), U9.3 (OUT)
/DCDC_OUT: C2.2, C5.2, C9.2, C12.2, L1.1, U5.14 (VDD_SOC_IN), U5.53 (VDD_SOC_IN), U5.77 (VDD_SOC_IN)
/FPGA_CFG0: JP9.2 (C), U8.N10 (CFG_0)
/FPGA_CFG1: JP8.2 (C), U8.P10 (CFG_1)
/FPGA_CFG2: JP7.2 (C), U8.R10 (CFG_2)
/FPGA_DONE: U5.59 (GPIO_AD_01), U8.P9 (DONE)
/FPGA_~HOLD: R35.2, U5.60 (GPIO_AD_00), U8.N8 (PB15A_HOLDN/DI/BUSY/CSSPIN/CEN)
/FPGA_~INIT: U5.58 (GPIO_AD_02), U8.T9 (INITN)
/FPGA_~PROGRAM: R34.2, U5.51 (GPIO_AD_07), U8.R9 (PROGRAMN)
/LED0: R25.1, U8.F15 (PR11C)
/LED1: R26.1, U8.E16 (PR11D)
/LED2: R27.1, U8.E15 (PR8B*)
/LED3: R28.1, U8.D16 (PR8A*)
/LED4: R29.1, U8.C16 (PR5A*)
/LED5: R30.1, U8.C15 (PR5B*)
/LED6: R31.1, U8.B16 (PR2A*)
/LED7: R32.1, U8.B15 (PR2B_S0_IN*)
/LED_B: R22.1, U5.10 (GPIO_03)
/LED_G: R21.1, U5.11 (GPIO_02)
/LED_R: R20.1, U5.12 (GPIO_01)
/MCU_SWD_CLK: J2.1, U5.45 (GPIO_AD_12)
/MCU_SWD_IO: J2.2, U5.44 (GPIO_AD_13)
/PMOD1_1: PMOD1.1, RN1.8 (R1.2)
/PMOD1_1x: RN1.1 (R1.1), U8.P2 (PL32B*)
/PMOD1_2: PMOD1.2, RN1.6 (R3.2)
/PMOD1_2x: RN1.3 (R3.1), U8.L1 (PL26A_PCLKT6_1*)
/PMOD1_3: PMOD1.3, RN2.8 (R1.2)
/PMOD1_3x: RN2.1 (R1.1), U8.J2 (PL23B_PCLKC7_1*)
/PMOD1_4: PMOD1.4, RN2.6 (R3.2)
/PMOD1_4x: RN2.3 (R3.1), U8.H2 (PL20B*)
/PMOD1_5: PMOD1.7, RN1.7 (R2.2)
/PMOD1_5x: RN1.2 (R2.1), U8.N1 (PL32A*)
/PMOD1_6: PMOD1.8, RN1.5 (R4.2)
/PMOD1_6x: RN1.4 (R4.1), U8.L2 (PL26B_PCLKC6_1*)
/PMOD1_7: PMOD1.9, RN2.7 (R2.2)
/PMOD1_7x: RN2.2 (R2.1), U8.J1 (PL23A_PCLKT7_1*)
/PMOD1_8: PMOD1.10, RN2.5 (R4.2)
/PMOD1_8x: RN2.4 (R4.1), U8.G1 (PL20A_GR_PCLK7_1*)
/PMOD2_1: PMOD2.1, RN3.8 (R1.2)
/PMOD2_1x: RN3.1 (R1.1), U8.G2 (PL14B*)
/PMOD2_2: PMOD2.2, RN3.6 (R3.2)
/PMOD2_2x: RN3.3 (R3.1), U8.E2 (PL8B*)
/PMOD2_3: PMOD2.3, RN4.8 (R1.2)
/PMOD2_3x: RN4.1 (R1.1), U8.C1 (PL5A*)
/PMOD2_4: PMOD2.4, RN4.6 (R3.2)
/PMOD2_4x: RN4.3 (R3.1), U8.B1 (PL2A*)
/PMOD2_5: PMOD2.7, RN3.7 (R2.2)
/PMOD2_5x: RN3.2 (R2.1), U8.F1 (PL14A*)
/PMOD2_6: PMOD2.8, RN3.5 (R4.2)
/PMOD2_6x: RN3.4 (R4.1), U8.D1 (PL8A*)
/PMOD2_7: PMOD2.9, RN4.7 (R2.2)
/PMOD2_7x: RN4.2 (R2.1), U8.C2 (PL5B*)
/PMOD2_8: PMOD2.10, RN4.5 (R4.2)
/PMOD2_8x: RN4.4 (R4.1), U8.B2 (PL2B*)
/PMOD3_1: PMOD3.1, RN5.8 (R1.2)
/PMOD3_1x: RN5.1 (R1.1), U8.D4 (PT9B)
/PMOD3_2: PMOD3.2, RN5.6 (R3.2)
/PMOD3_2x: RN5.3 (R3.1), U8.C6 (PT22A)
/PMOD3_3: PMOD3.3, RN6.8 (R1.2)
/PMOD3_3x: RN6.1 (R1.1), U8.B7 (PT27B_PCLKC0_1)
/PMOD3_4: PMOD3.4, RN6.6 (R3.2)
/PMOD3_4x: RN6.3 (R3.1), U8.C7 (PT27A_PCLKT0_1)
/PMOD3_5: PMOD3.7, RN5.7 (R2.2)
/PMOD3_5x: RN5.2 (R2.1), U8.C4 (PT11A)
/PMOD3_6: PMOD3.8, RN5.5 (R4.2)
/PMOD3_6x: RN5.4 (R4.1), U8.B6 (PT22B)
/PMOD3_7: PMOD3.9, RN6.7 (R2.2)
/PMOD3_7x: RN6.2 (R2.1), U8.A7 (PT29A_PCLKT0_0)
/PMOD3_8: PMOD3.10, RN6.5 (R4.2)
/PMOD3_8x: RN6.4 (R4.1), U8.A8 (PT29B_PCLKC0_0)
/PMOD4_1: PMOD4.1, RN7.8 (R1.2)
/PMOD4_1x: RN7.1 (R1.1), U8.B11 (PT49A)
/PMOD4_2: PMOD4.2, RN7.6 (R3.2)
/PMOD4_2x: RN7.3 (R3.1), U8.B12 (PT56A)
/PMOD4_3: PMOD4.3, RN8.8 (R1.2)
/PMOD4_3x: RN8.1 (R1.1), U8.B13 (PT60A)
/PMOD4_4: PMOD4.4, RN8.6 (R3.2)
/PMOD4_4x: RN8.3 (R3.1), U8.B14 (PT67A)
/PMOD4_5: PMOD4.7, RN7.7 (R2.2)
/PMOD4_5x: RN7.2 (R2.1), U8.A12 (PT53B)
/PMOD4_6: PMOD4.8, RN7.5 (R4.2)
/PMOD4_6x: RN7.4 (R4.1), U8.A13 (PT65A)
/PMOD4_7: PMOD4.9, RN8.7 (R2.2)
/PMOD4_7x: RN8.2 (R2.1), U8.A14 (PT65B)
/PMOD4_8: PMOD4.10, RN8.5 (R4.2)
/PMOD4_8x: RN8.4 (R4.1), U8.A15 (PT67B)
/PMOD5_1: PMOD5.1, RN9.8 (R1.2)
/PMOD5_1x: RN9.1 (R1.1), U8.F16 (PR14A*)
/PMOD5_2: PMOD5.2, RN9.6 (R3.2)
/PMOD5_2x: RN9.3 (R3.1), U8.G16 (PR20A_GR_PCLK2_1*)
/PMOD5_3: PMOD5.3, RN10.8 (R1.2)
/PMOD5_3x: RN10.1 (R1.1), U8.J16 (PR23A_PCLKT2_1*)
/PMOD5_4: PMOD5.4, RN10.6 (R3.2)
/PMOD5_4x: RN10.3 (R3.1), U8.L16 (PR26A_PCLKT3_1*)
/PMOD5_5: PMOD5.7, RN9.7 (R2.2)
/PMOD5_5x: RN9.2 (R2.1), U8.G15 (PR14B*)
/PMOD5_6: PMOD5.8, RN9.5 (R4.2)
/PMOD5_6x: RN9.4 (R4.1), U8.H15 (PR20B*)
/PMOD5_7: PMOD5.9, RN10.7 (R2.2)
/PMOD5_7x: RN10.2 (R2.1), U8.J15 (PR23B_PCLKC2_1*)
/PMOD5_8: PMOD5.10, RN10.5 (R4.2)
/PMOD5_8x: RN10.4 (R4.1), U8.L15 (PR26B_PCLKC3_1*)
/POR_B: R17.1, SW2.1, U5.22 (POR_B), U6.2 (~RESET~)
/RAM1_CLK: U7.6 (CLK), U8.B9 (PT38A_GR_PCLK1_0)
/RAM1_D0: U7.5 (DI(IO0)), U8.B10 (PT44A)
/RAM1_D1: U7.2 (DO(IO1)), U8.A10 (PT42B)
/RAM1_D2: U7.3 (IO2), U8.A11 (PT53A)
/RAM1_D3: U7.7 (IO3), U8.B8 (PT35B_PCLKC1_0)
/RAM1_~CS~: U7.1 (~CS), U8.A9 (PT42A)
/RAM2_CLK: U8.A4 (PT6B), U10.6 (CLK)
/RAM2_D0: U8.A5 (PT18A), U10.5 (DI(IO0))
/RAM2_D1: U8.B3 (PT4B), U10.2 (DO(IO1))
/RAM2_D2: U8.B4 (PT11B), U10.3 (IO2)
/RAM2_D3: U8.A3 (PT6A), U10.7 (IO3)
/RAM2_~CS~: U8.A2 (PT4A), U10.1 (~CS)
/SW_USER: C40.1, R33.1, SW1.1, U8.F14 (PR5D)
/USB_DM: J1.A7 (D-), J1.B7 (D-), U5.32 (USB_OTG1_DN)
/USB_DP: J1.A6 (D+), J1.B6 (D+), U5.33 (USB_OTG1_DP)
/USB_SHIELD: J1.S1 (SHIELD), R1.1
/VBUS_UNFILTERED: FB1.2, J1.A4 (VBUS), J1.A9 (VBUS), J1.B4 (VBUS), J1.B9 (VBUS)
GND: C1.1, C2.1, C3.1, C4.1, C5.1, C6.1, C7.1, C8.1, C9.1, C10.1, C11.1, C12.1, C13.1, C14.1, C15.1, C18.1, C19.1, C20.1, C23.1, C24.1, C25.1, C26.1, C27.1, C28.1, C29.1, C30.1, C31.1, C32.1, C33.1, C34.1, C35.1, C36.1, C37.1, C38.1, C39.1, C40.2, C41.1, C42.1, C43.1, C44.1, D2.1 (K), D3.1 (K), D4.1 (K), D5.1 (K), D6.1 (K), D7.1 (K), D8.1 (K), D9.1 (K), J1.A1 (GND), J1.A12 (GND), J1.B1 (GND), J1.B12 (GND), J2.4, J3.2, J4.1, J5.2, JP1.3 (B), JP2.3 (B), JP3.3 (B), JP4.3 (B), JP5.3 (B), JP6.3 (B), JP7.3 (B), JP8.3 (B), JP9.3 (B), PMOD1.5, PMOD1.11, PMOD2.5, PMOD2.11, PMOD3.5, PMOD3.11, PMOD4.5, PMOD4.11, PMOD5.5, PMOD5.11, R1.2, R6.2, R7.2, R10.1, R12.1, R23.1, R34.1, SW1.2, SW2.2, U1.2 (GND), U2.1 (GND), U3.2 (GND), U4.4 (GND), U5.16 (VSS), U5.20 (DCDC_GND), U5.23 (TEST_MODE), U5.27 (RTC_XTALI), U5.30 (VSS), U5.34 (NGND_KEL0), U5.41 (VSSA_ADC_3P3), U5.54 (VSS), U5.78 (VSS), U6.1 (GND), U7.4 (GND), U8.A1 (GND), U8.A16 (GND), U8.D2 (GND), U8.D15 (GND), U8.F8 (GND), U8.F9 (GND), U8.G8 (GND), U8.G10 (GND), U8.H1 (GND), U8.H8 (GND), U8.H9 (GND), U8.H10 (GND), U8.H16 (GND), U8.J8 (GND), U8.J9 (GND), U8.J10 (GND), U8.K6 (GND), U8.K7 (GND), U8.K8 (GND), U8.K9 (GND), U8.K10 (GND), U8.N2 (GND), U8.N15 (GND), U8.T1 (GND), U8.T5 (GND), U8.T12 (GND), U8.T16 (GND), U9.2 (GND), U10.4 (GND), Y1.2, Y1.4
unnamed: C8.2, C10.2, U5.40 (NVCC_PLL)
unnamed: C11.2, U5.37 (XTALI), Y1.1
unnamed: C13.2, C15.2, U5.35 (VDD_HIGH_CAP)
unnamed: C14.2, U5.38 (XTALO), Y1.3
unnamed: C16.1, U1.1 (BS)
unnamed: C16.2, L2.1, U1.6 (LX)
unnamed: C17.1, U3.1 (BS)
unnamed: C17.2, L3.1, U3.6 (LX)
unnamed: C18.2, U5.26 (VDD_SNVS_CAP)
unnamed: C19.2, R8.1, U5.15 (DCDC_PSWITCH)
unnamed: C20.2, C24.2, U5.31 (VDD_USB_CAP)
unnamed: C21.1, R9.1, R10.2, U1.3 (FB)
unnamed: C22.1, R11.1, R12.2, U3.3 (FB)
unnamed: D1.2 (RK), R20.2
unnamed: D1.3 (GK), R21.2
unnamed: D1.4 (BK), R22.2
unnamed: D2.2 (A), R25.2
unnamed: D3.2 (A), R26.2
unnamed: D4.2 (A), R27.2
unnamed: D5.2 (A), R28.2
unnamed: D6.2 (A), R29.2
unnamed: D7.2 (A), R30.2
unnamed: D8.2 (A), R31.2
unnamed: D9.2 (A), R32.2
unnamed: J1.A5 (CC1), R6.1
unnamed: J1.B5 (CC2), R7.1
unnamed: L1.2, U5.19 (DCDC_LP)
unnamed: R2.2, U1.4 (EN)
unnamed: R3.2, U3.4 (EN)
VBUS: C1.2, C3.2, C4.2, C6.2, C7.2, FB1.1, J3.1, J5.1, R2.1, R3.1, U1.5 (IN), U2.3 (VIN), U3.5 (IN), U5.29 (USB_OTG1_VBUS)

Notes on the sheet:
Ra = Rb * (0.6 / (Vout - 0.6)) Vout = (1 + Ra/Rb) * 0.6
Vout = (1 + 15e3/18e3) * 0.6 = 1.1V
Open Drain 140ms delay
PSWITCH RC DELAY
SRC_BOOT_MODE[1:0] 00: boot using fuses. 01: serial download (usb/uart) 10: "internal boot" 11: reserved Default fuses are set to serial download.
DNP in production
2V5: 200mA max
1V1: 2A max
3V3: 2A max
Vout = (1 + 15e3/3.3e3) * 0.6 = 3.33V
ECP5 CFGMDN[2:0] 001: Slave SPI 101: Slave Serial 111: Slave Parallell (N/A) 010: Master SPI Note: Use 4K7 for pull-up and <500R for pull-down Default is internal pull-up.
Flash shared between iMX and ECP5
Pull ~PROGRAM~ low to stall ECP5 in initialization state until the MCU boots. Should prevent a race to use the flash first.
In Master SPI mode, PB15A is the CS pin. There is no HOLD pin. In Slave SPI mode, PB15A is HOLD, and PB13A is CS. Connect 0R when in Master SPI mode.
"It is recommended to connect RTC_XTALI to GND and keep RTC_XTALO unconnected."
Errata
RevA 0.1: - iMX ROM bootloader freezes because the UART RX pin is pulled low by the FPGA during boot. (FPGA pin is PL35B_VREF_1_6) A 4K7 pull-up is probably not enough, the voltage drops to 2.9V. Workaround: Bodge a 1K pull-up or disconnect pin. - Wrong load caps for the xtal. Should be 20pF. - SWD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
TODO
RevA 0.2: [X] Add strong 1K pull-ups on UART RX and TX lines. [X] Tune LED brightness. 10K looks good. [X] Add USB connector TH pads solderpaste layer. [X] Fix incorrect silkscreen for bootmode and swd. [ ] Replace 0R resistors on back with solderjumpers. Need to put resistors on top layer. [ ] Fix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

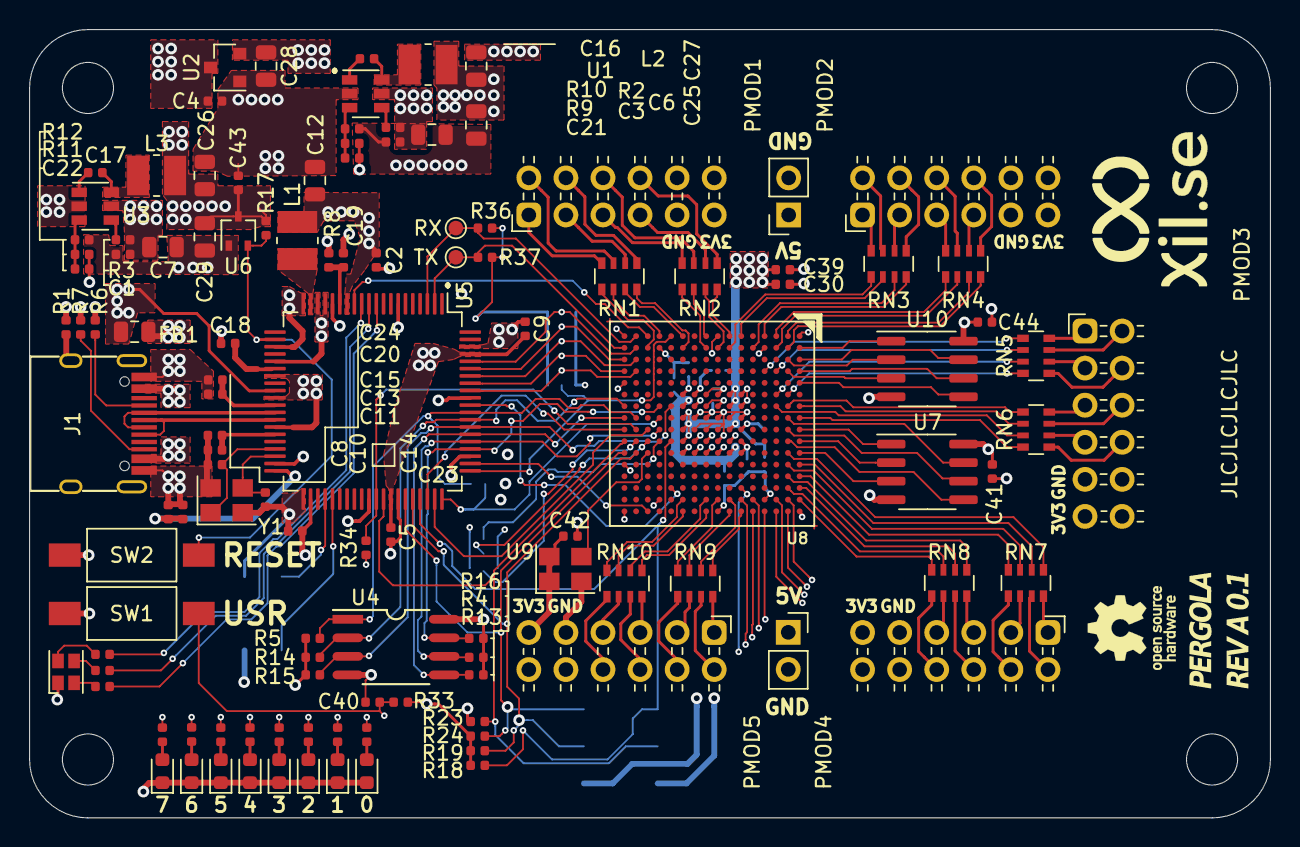
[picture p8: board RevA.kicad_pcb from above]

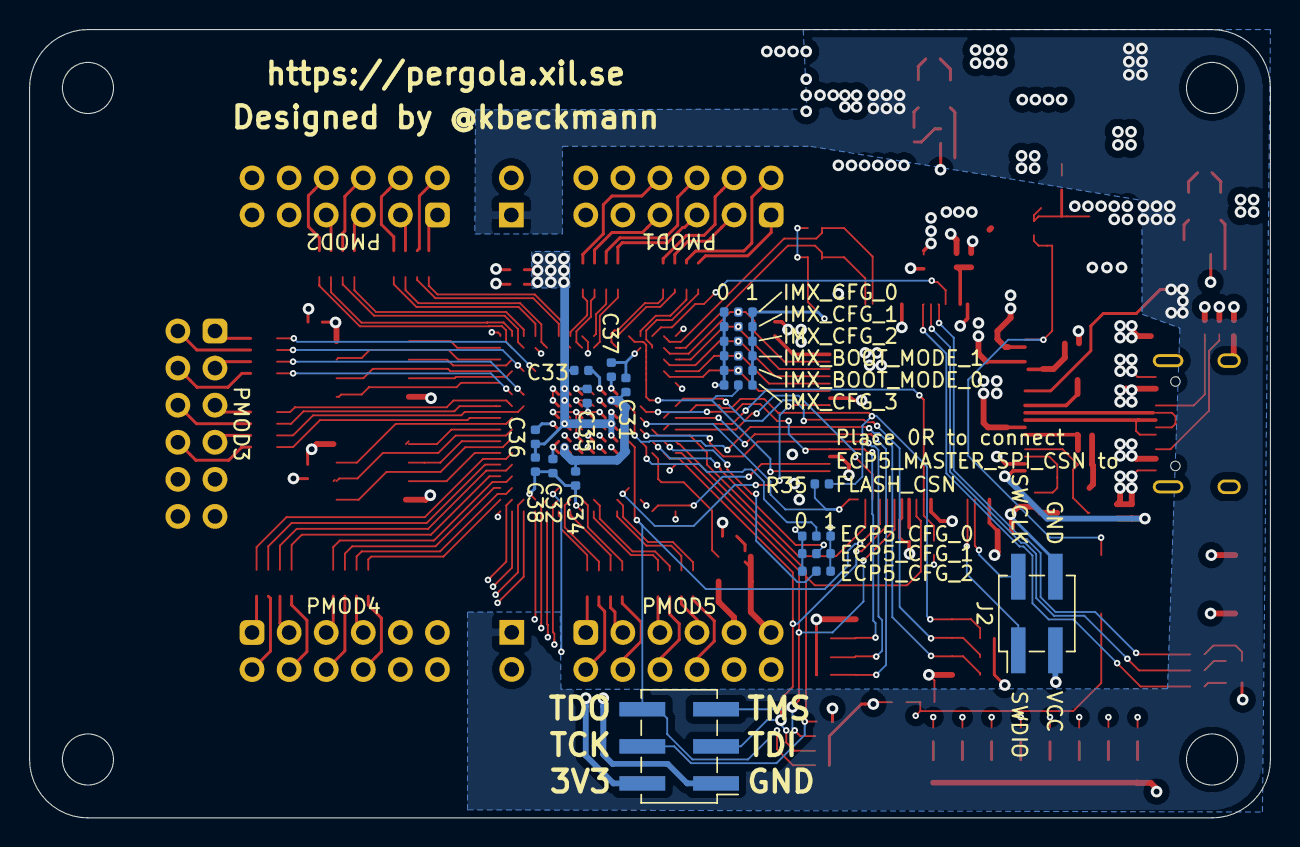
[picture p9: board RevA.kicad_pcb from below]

Board: 4 copper layers, 85.0 x 54.0 mm, 145 parts (20 on the bottom side), 175 nets.

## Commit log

2019-11-17 Pergola RevA 0.1
    [RevA-B_Cu.gbr, RevA-B_Mask.gbr, RevA-B_Paste.gbr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]
2019-11-18 Update BOM and pdf to match RevA 0.1
    [RevA_bom.csv]
2019-12-01 Add errata/todo
    [RevA.sch]
2019-12-01 Update errata/todo
    [RevA.sch]
2019-12-01 Changed xtal load caps to 20pF
    [RevA.sch]
2019-12-08 RevA 0.2 updates
    [RevA.kicad_pcb, RevA.sch]
2019-12-09 Fix errata, swd io/clk are swapped on the silk
    [RevA.kicad_pcb, RevA.sch]
2019-12-20 Vendor footprints/symbols
    [RevA.kicad_pcb]
2019-12-20 Rename gerber directory
    [RevA-B_Cu.gbr, RevA-B_Mask.gbr, RevA-B_Paste.gbr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]
2019-12-21 hardware: Add USB TH pads solderpaste layer
    This was not being done before, leading to
    stencils missing the through-hole pads for
    the USB connector.
    [RevA.kicad_pcb, RevA.sch]
2019-12-21 hardware: Fix silkscreen for bootmode and swd
    - SWD IO and CLK were swapped on the silk.
    - IMX_BOOT_MODE_0 and IMX_BOOT_MODE_1 were swapped on the silk.
    [RevA.kicad_pcb, RevA.sch]
2019-12-28 Add nmigen board wip
2020-04-19 Add note about SW_USR
    [RevA.sch]
